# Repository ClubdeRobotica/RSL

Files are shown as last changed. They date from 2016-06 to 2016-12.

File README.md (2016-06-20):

# RSL

Repositorio del proyecto RSL del Club de Robótica de la UTN-FRC

#Mini Tutorial de Github

Para hacer un mini tutorial de como usar GIT, pueden entrar a https://try.github.io/

# Instrucciones:

Se pueden subir y bajar todos los archivos desde la página

https://github.com/ClubdeRobotica/RSL.git

Para subir un archivo (prueba.md) desde consola se hace lo siguiente:

1 Inicializar git

git init

2 Se agrega prueba, igual que en el svn

git add prueba.md

3 Ponemos un comentario describiendo lo que estamos haciendo

git commit -m "primera commit de prueba"

git remote add origin https://github.com/ClubdeRobotica/RSL.git

4 La primera vez va a devolver un error porque porque no tenemos configurado el usuario.Primero configurar el usuario:

git config --global user.name usuario

y volves al paso 3

5 Se sube el archivo

git push -u origin master

Pide usuario y contraseña para subir un archivo, hay que estar agregado al repositorio para poder subir

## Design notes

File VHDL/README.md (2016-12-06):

# Logica en VHDL de un RSL 
	
Sintetizado en FPGA Spartan 3E XC3S100E-TQ144

Código en VHDL:

Maquina de estado para controlar la logica de los motores y decisiones.

PWM con instanciacion de un contador y un comparador

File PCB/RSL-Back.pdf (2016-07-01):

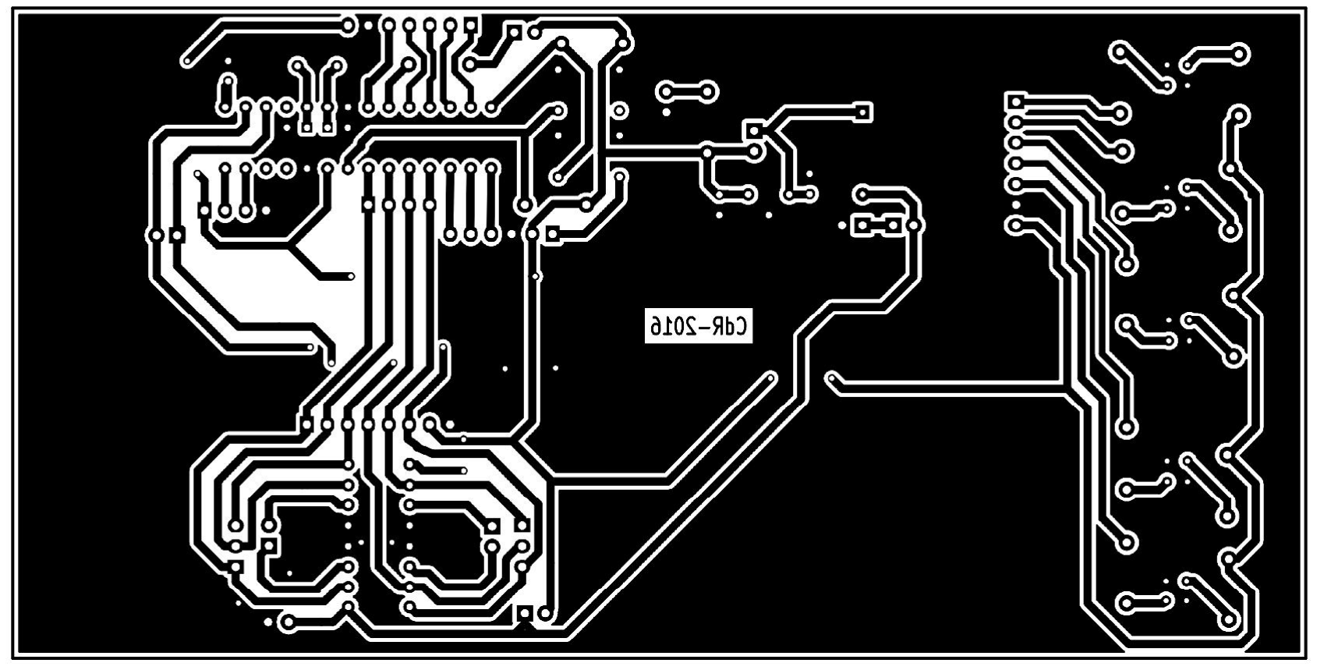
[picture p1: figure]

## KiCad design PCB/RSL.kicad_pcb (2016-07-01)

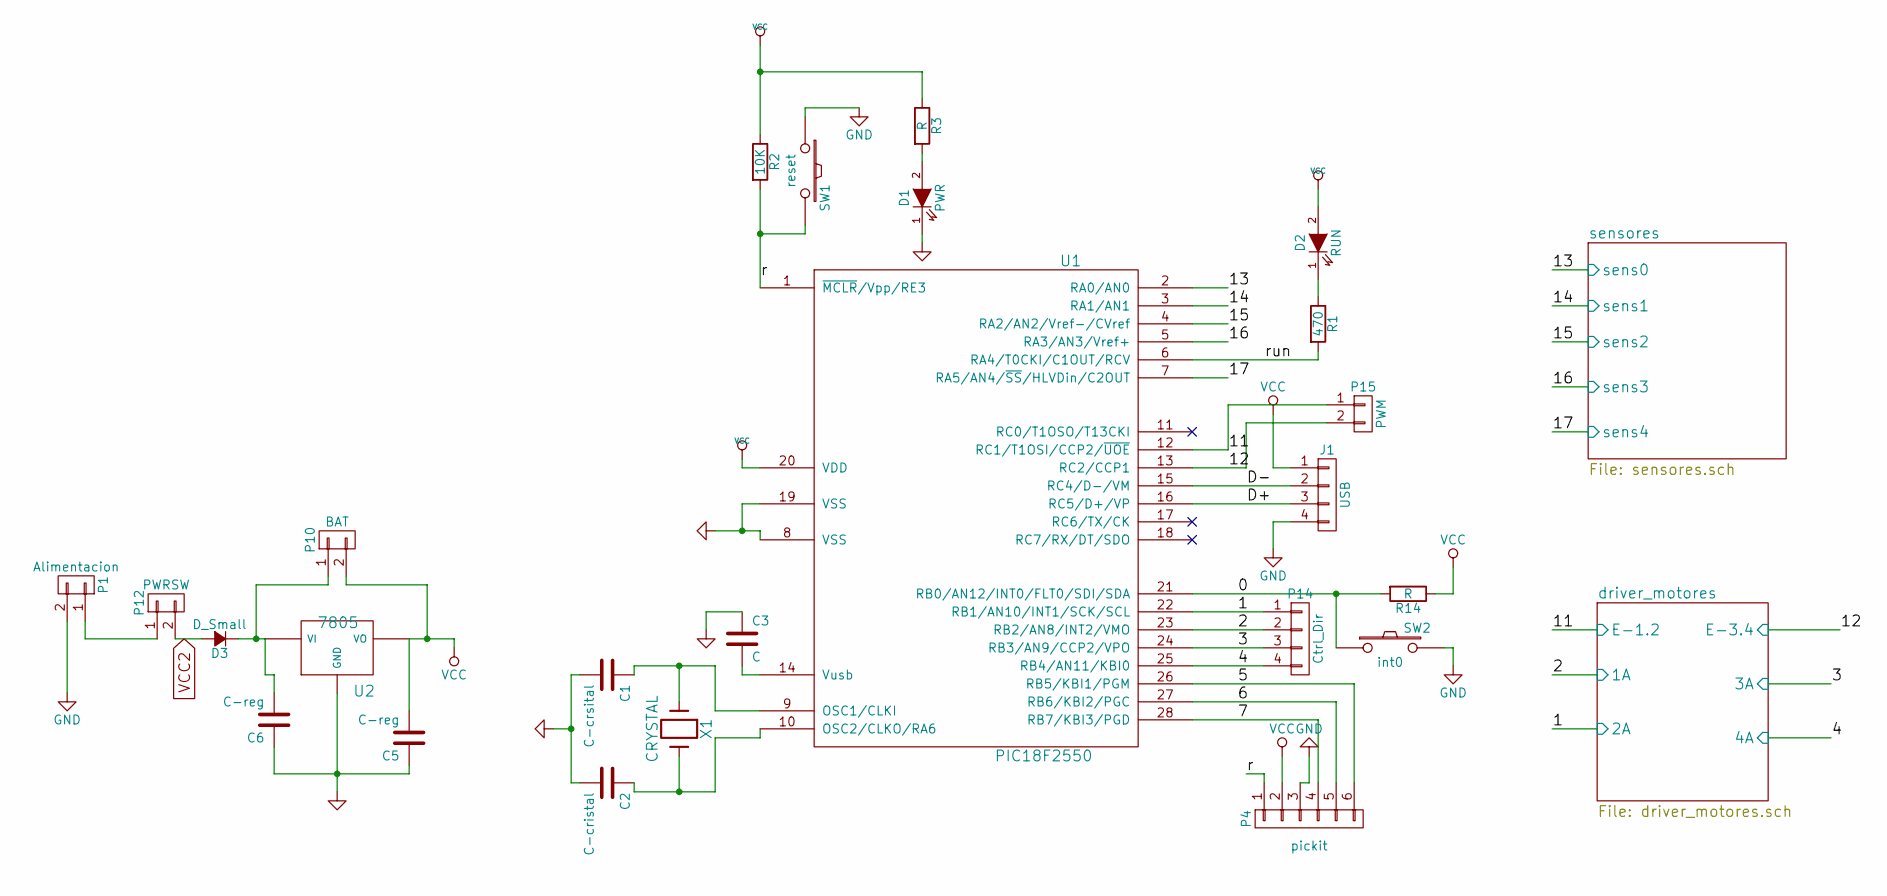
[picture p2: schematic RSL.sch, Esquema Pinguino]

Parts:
C1: C-crsital; C_Disc_D3_P2.5
C2: C-cristal; C_Disc_D3_P2.5
C3: C; C_Disc_D3_P2.5
C5, C6: C-reg; C_Disc_D3_P2.5
D1: PWR; LED-5MM
D2: RUN; LED-5MM
D3: D_Small; Diode_DO-35_SOD27_Horizontal_RM10
J1: USB; Pin_Header_Straight_1x04
P1: Alimentacion; Pin_Header_Straight_1x02
P4: pickit; Socket_Strip_Straight_1x06
P10: BAT; Pin_Header_Straight_1x02
P12: PWRSW; Pin_Header_Straight_1x02
P14: Ctrl_Dir; Pin_Header_Straight_1x04
P15: PWM; Pin_Header_Straight_1x02
R1: 470; Resistor_Horizontal_RM7mm
R2: 10K; Resistor_Horizontal_RM7mm
R3, R14: R; Resistor_Horizontal_RM7mm
SW1: reset; SW_PUSH_SMALL
SW2: int0; SW_PUSH_SMALL
U1: PIC18F2550; DIP-28_W7.62mm
U2: 7805; TO-92_Molded_Wide
X1: CRYSTAL; Crystal_HC49-U_Vertical

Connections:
/0: R14.2, SW2.1, U1.21 (RB0/AN12/INT0/FLT0/SDI/SDA)
/5: P4.6, U1.26 (RB5/KBI1/PGM)
/6: P4.5, U1.27 (RB6/KBI2/PGC)
/7: P4.4, U1.28 (RB7/KBI3/PGD)
/D+: J1.3, U1.16 (RC5/D+/VP)
/D-: J1.2, U1.15 (RC4/D-/VM)
/driver_motores/1A: P14.2, U1.23 (RB2/AN8/INT2/VMO); also elsewhere on the board
/driver_motores/2A: P14.1, U1.22 (RB1/AN10/INT1/SCK/SCL); also elsewhere on the board
/driver_motores/3A: P14.3, U1.24 (RB3/AN9/CCP2/VPO); also elsewhere on the board
/driver_motores/4A: P14.4, U1.25 (RB4/AN11/KBI0); also elsewhere on the board
/driver_motores/E-1.2: P15.1, U1.12 (RC1/T1OSI/CCP2/~UOE); also elsewhere on the board
/driver_motores/E-3.4: P15.2, U1.13 (RC2/CCP1); also elsewhere on the board
/r: P4.1, R2.2, SW1.2, U1.1 (~MCLR~/Vpp/RE3)
/run: R1.2, U1.6 (RA4/T0CKI/C1OUT/RCV)
/sensores/sens0: U1.2 (RA0/AN0); also elsewhere on the board
/sensores/sens1: U1.3 (RA1/AN1); also elsewhere on the board
/sensores/sens2: U1.4 (RA2/AN2/Vref-/CVref); also elsewhere on the board
/sensores/sens3: U1.5 (RA3/AN3/Vref+); also elsewhere on the board
/sensores/sens4: U1.7 (RA5/AN4/~SS~/HLVDin/C2OUT); also elsewhere on the board
GND: C1.2, C2.2, C3.1, C5.1, C6.1, D1.1 (K), J1.4, P1.2, P4.3, SW1.1, SW2.2, U1.8 (VSS), U1.19 (VSS), U2.2 (GND); also elsewhere on the board
unnamed: C1.1, U1.9 (OSC1/CLKI), X1.1
unnamed: C2.1, U1.10 (OSC2/CLKO/RA6), X1.2
unnamed: C3.2, U1.14 (Vusb)
unnamed: C6.2, D3.1 (K), P10.1, U2.1 (VI)
unnamed: D1.2 (A), R3.2
unnamed: D2.1 (K), R1.1
unnamed: P1.1, P12.1
VCC: C5.2, D2.2 (A), J1.1, P4.2, P10.2, R2.1, R3.1, R14.1, U1.20 (VDD), U2.3 (VO); also elsewhere on the board
VCC2: D3.2 (A), P12.2; also elsewhere on the board

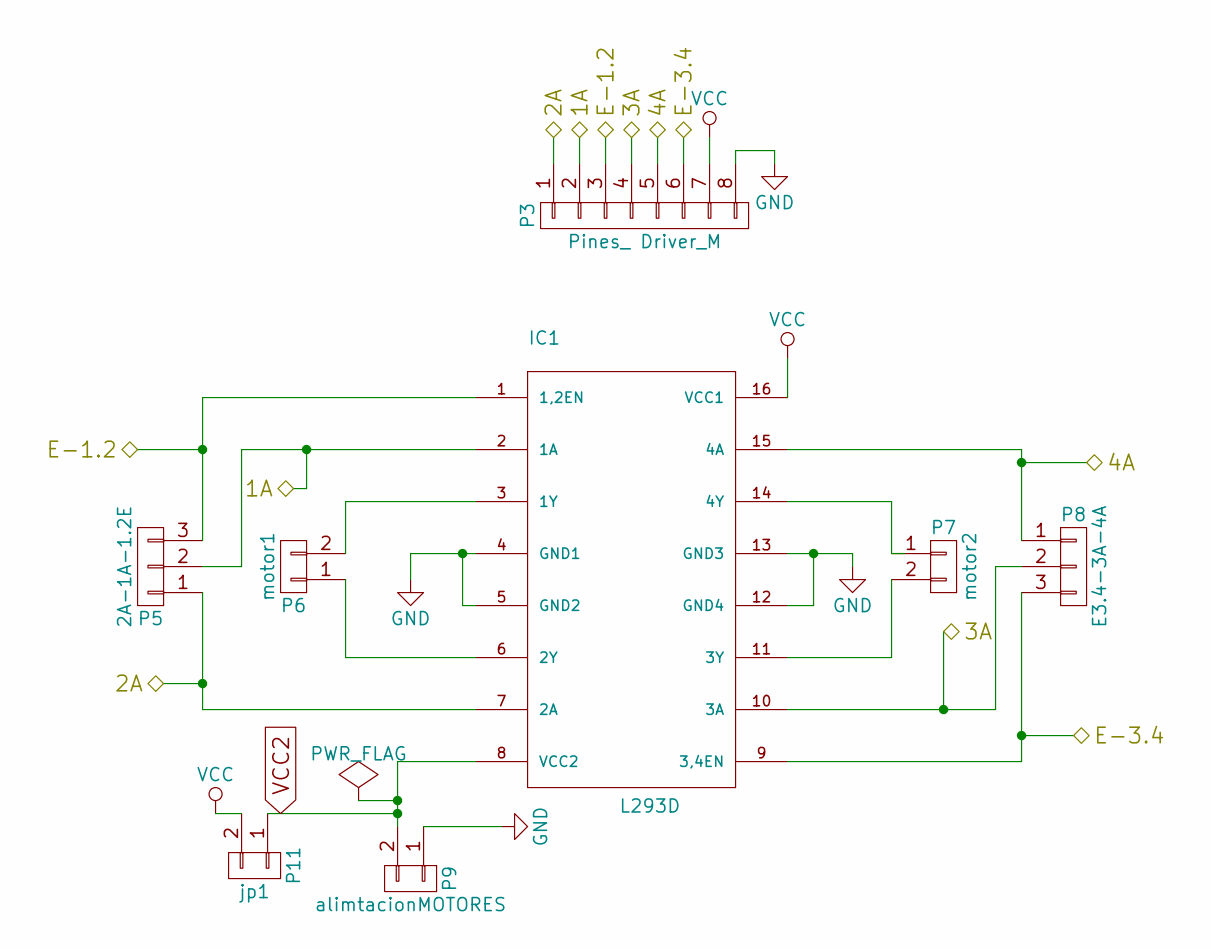
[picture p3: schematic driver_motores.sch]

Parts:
IC1: L293D; DIP-16_W7.62mm
P3: Pines_ Driver_M; Socket_Strip_Straight_1x08
P5: 2A-1A-1.2E; Pin_Header_Straight_1x03
P6: motor1; Pin_Header_Straight_1x02
P7: motor2; Pin_Header_Straight_1x02
P8: E3.4-3A-4A; Pin_Header_Straight_1x03
P9: alimtacionMOTORES; Pin_Header_Straight_1x02
P11: jp1; Pin_Header_Straight_1x02

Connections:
/driver_motores/1A: IC1.2 (1A), P3.2, P5.2; also elsewhere on the board
/driver_motores/2A: IC1.7 (2A), P3.1, P5.1; also elsewhere on the board
/driver_motores/3A: IC1.10 (3A), P3.4, P8.2; also elsewhere on the board
/driver_motores/4A: IC1.15 (4A), P3.5, P8.1; also elsewhere on the board
/driver_motores/E-1.2: IC1.1 (1,2EN), P3.3, P5.3; also elsewhere on the board
/driver_motores/E-3.4: IC1.9 (3,4EN), P3.6, P8.3; also elsewhere on the board
GND: IC1.4 (GND1), IC1.5 (GND2), IC1.12 (GND4), IC1.13 (GND3), P3.8, P9.1; also elsewhere on the board
unnamed: IC1.3 (1Y), P6.2
unnamed: IC1.6 (2Y), P6.1
unnamed: IC1.11 (3Y), P7.2
unnamed: IC1.14 (4Y), P7.1
VCC: IC1.16 (VCC1), P3.7, P11.2; also elsewhere on the board
VCC2: IC1.8 (VCC2), P9.2, P11.1; also elsewhere on the board

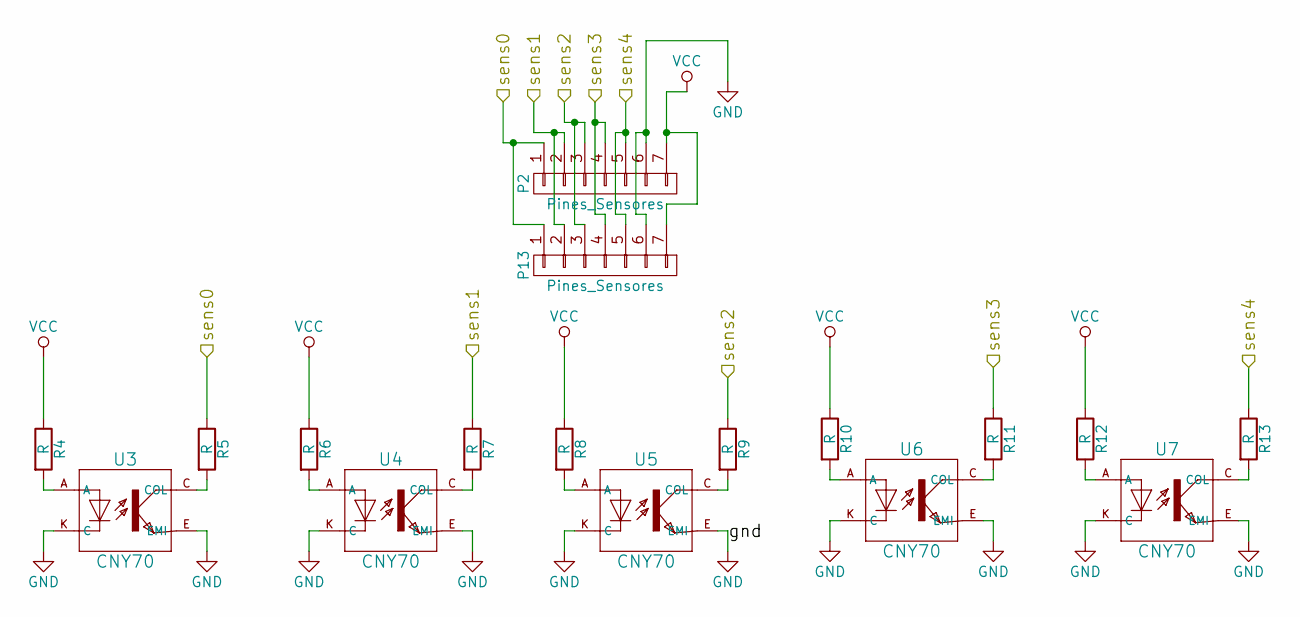
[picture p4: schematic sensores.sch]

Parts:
P2, P13: Pines_Sensores; Socket_Strip_Straight_1x07
R4, R5, R6, R7, R8, R9, R10, R11, R12, R13: R; Resistor_Horizontal_RM7mm
U3, U4, U5, U6, U7: CNY70; cny70-4

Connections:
/sensores/sens0: P2.1, P13.1, R5.1; also elsewhere on the board
/sensores/sens1: P2.2, P13.2, R7.1; also elsewhere on the board
/sensores/sens2: P2.3, P13.3, R9.1; also elsewhere on the board
/sensores/sens3: P2.4, P13.4, R11.1; also elsewhere on the board
/sensores/sens4: P2.5, P13.5, R13.1; also elsewhere on the board
GND: P2.6, P13.6, U3.E (EMI), U3.K (C), U4.E (EMI), U4.K (C), U5.E (EMI), U5.K (C), U6.E (EMI), U6.K (C), U7.E (EMI), U7.K (C); also elsewhere on the board
unnamed: R4.2, U3.A
unnamed: R5.2, U3.C (COL)
unnamed: R6.2, U4.A
unnamed: R7.2, U4.C (COL)
unnamed: R8.2, U5.A
unnamed: R9.2, U5.C (COL)
unnamed: R10.2, U6.A
unnamed: R11.2, U6.C (COL)
unnamed: R12.2, U7.A
unnamed: R13.2, U7.C (COL)
VCC: P2.7, P13.7, R4.1, R6.1, R8.1, R10.1, R12.1; also elsewhere on the board

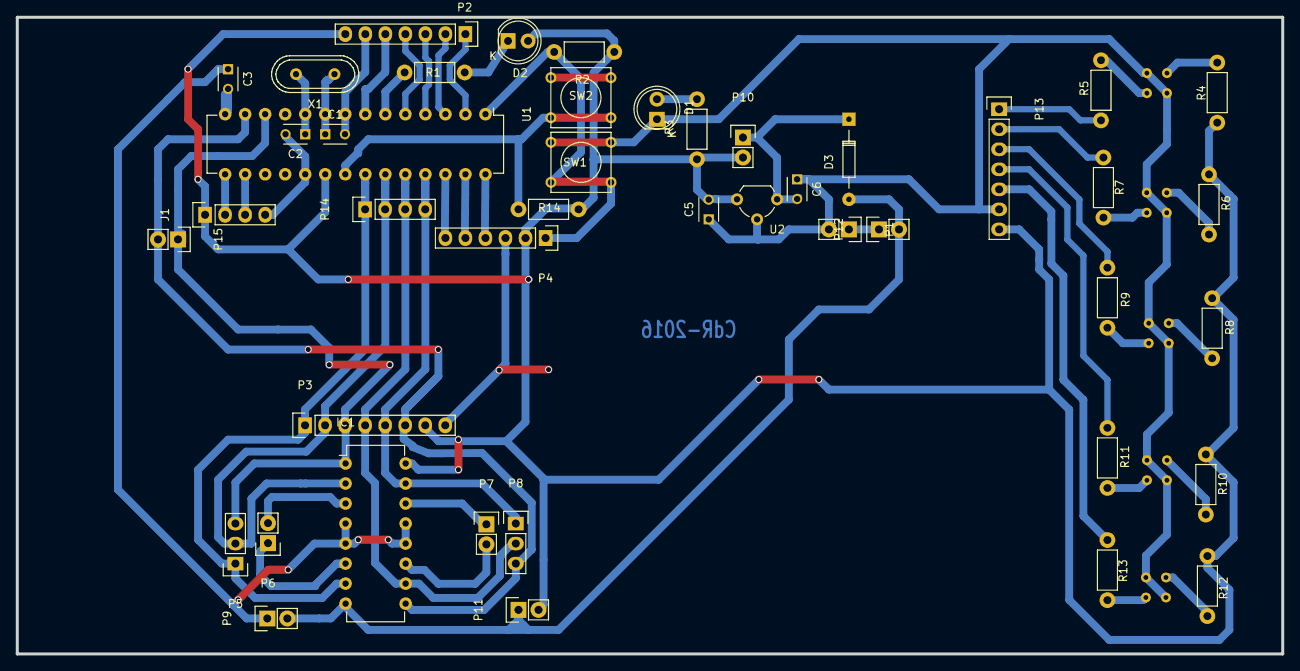
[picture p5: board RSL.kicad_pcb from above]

Board: 2 copper layers, 160.5 x 80.8 mm, 49 parts (0 on the bottom side), 43 nets.

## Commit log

2016-05-20 segundo commit
    [Pinguino_elelectronlibre_V1.brd, Pinguino_elelectronlibre_V1.sch]
2016-05-20 Indicacione de como subir un archivo en el README.md
2016-05-20 Indicaciones de como subir un archivo en el README.md
2016-06-03 indicaciones como configurar el usuario
2016-06-20 agregado link a tutorial online de github
2016-07-01 Archivos del PCB
    [RSL.kicad_pcb, RSL.sch, driver_motores.sch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]
